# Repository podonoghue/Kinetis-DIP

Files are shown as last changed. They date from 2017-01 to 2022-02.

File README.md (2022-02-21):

# Kinetis-DIP
Kinetis MK22FN512VLH12 module in DIP format

The hardware design is an Altium designer project.  

Refer to the PDFs in the Project Outputs directory 

<a href="https://raw.githubusercontent.com/podonoghue/Kinetis-DIP/master/Hardware/Project%20Outputs%20for%20KinetisDIP/KinetisDIP.PDF">Main Board</img></a>

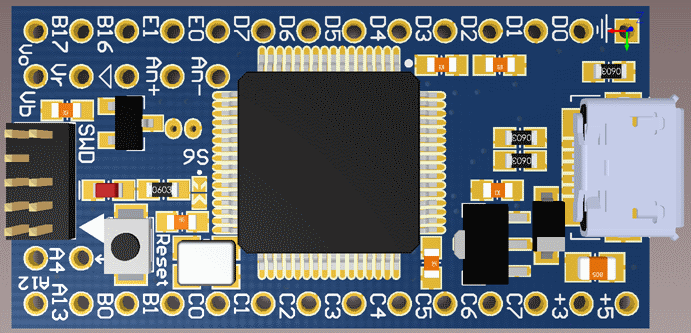
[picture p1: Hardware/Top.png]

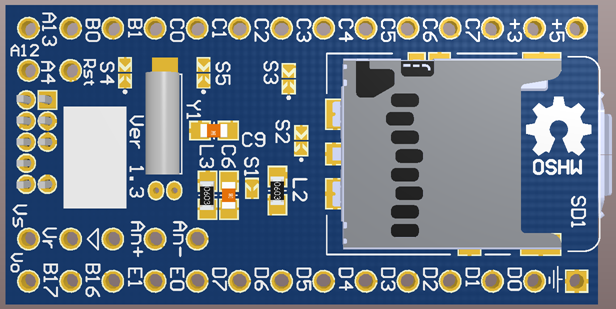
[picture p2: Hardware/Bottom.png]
An image Board Image - Bottom


====
PCBs may be ordered from OSH park

Main board

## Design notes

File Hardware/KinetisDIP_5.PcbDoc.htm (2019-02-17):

Reporting Options

# File in Previous Format

Date | : | 10/09/2017
Time | : | 6:38:27 PM
Filename | : | C:\Users\podonoghue\Documents\Development\PCB\Kinetis-DIP\Hardware\KinetisDIP_5.PcbDoc

Version | Warning
6.3 | CAUTION - Via connections to both hatched and solid signal layer polygons are now controlled by the polygon connect style rule. Re-pouring polygons may result in physical copper differences.
Summer 09 | CAUTION - File contains old violation objects. These violations are no longer supported & will not be loaded. Please run DRC after opening this file in order to refresh the violations.
Summer 09 | CAUTION - Existing testpoint rules and settings are used as fabrication testpoint information.
Altium Designer update 19 | CAUTION - Air Gap Width attribute was introduced to Polygon Connect Style Rule. Air Gap Width attribute now controls the distance between poured polygon and pads on the same net - this value was previosuly taken from clearance rule while ignoring net subscope leading to sometime unexpected results.
Release 13 | CAUTION - Silkscreen Over Component Pads Rules are converted to Silk To Solder Mask Clearance Rules. Suggest examining rule scopes for accuracy.
Release 14 | CAUTION - The Differential Pairs Routing rule added support for control of the width. Be aware that Width rules pertaining to differential pairs need to be manually moved to the Differential Pairs Routing rule.

This file was generated by an earlier version of the software

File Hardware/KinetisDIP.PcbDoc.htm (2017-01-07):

Reporting Options

# File in Previous Format

Date | : | 5/07/2016
Time | : | 8:55:03 AM
Filename | : | C:\Users\podonoghue\Documents\Development\USBDM\PCB\KinetisDIP\KinetisDIP.PcbDoc

Version | Warning
Summer 09 | CAUTION - File contains old violation objects. These violations are no longer supported & will not be loaded. Please run DRC after opening this file in order to refresh the violations.
Summer 09 | CAUTION - Existing testpoint rules and settings are used as fabrication testpoint information.
Release 12 | CAUTION - Air Gap Width previously controlled by Clearance rule is now controlled by Polygon Connect Style rule's newly introduced Air Gap Width (set to default value). Suggest reviewing each Polygon Connect Style rule's Air Gap Width attribute for correctness.
Release 13 | CAUTION - Silkscreen Over Component Pads Rules are converted to Silk To Solder Mask Clearance Rules. Suggest examining rule scopes for accuracy.

This file was generated by an earlier version of the software

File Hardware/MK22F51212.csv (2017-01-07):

Family | MK22F51212 | mk
Device | MK22FN512VDC12 | K22P121M120SF7RM | BGA_121
Device | MK22FN512VLL12 | K22P121M120SF7RM | LQFP_100
Device | MK22FN512VLH12 | K22P121M120SF7RM | LQFP_64
Device | MK22FN512VMP12 | K22P121M120SF7RM | BGA_64
Device | FRDM_K22F | K22P121M120SF8RM | FRDM_K22F
Device | MK22F_Module | K22P121M120SF8RM | MK22F_DIPModule
Key | Pin Name | pkg BGA_121 | pkg LQFP_100 | pkg LQFP_64 | pkg BGA_64 | Pkg FRDM_K22F | Pkg MK22F_DIPModule | Reset | Default | ALT0 | ALT1 | ALT2 | ALT3 | ALT4 | ALT5 | ALT6 | ALT7 | Seq | 121 BGA | 100 LQFP | 64 LQFP | 64 BGA
Pin | PTE0/CLKOUT32K | E4 | p1 | p1 | A1 | D14/J2_18/ConTx | p10_E0 | ADC1_SE4a |  | ADC1_SE4a | PTE0/CLKOUT32K | SPI1_PCS1 | UART1_TX |  |  | I2C1_SDA | RTC_CLKOUT | 1 | E4 | 1 | 1 | A1
Pin | PTE1/LLWU_P0 | E3 | p2 | p2 | B1 | D15/J2_19/ConRx | p11_E1 | ADC1_SE5a |  | ADC1_SE5a | PTE1/LLWU_P0 | SPI1_SOUT | UART1_RX |  |  | I2C1_SCL | SPI1_SIN | 2 | E3 | 2 | 2 | B1
Pin | PTE2/LLWU_P1 | E2 | p3 | * | * | * | * | ADC1_SE6a |  | ADC1_SE6a | PTE2/LLWU_P1 | SPI1_SCK | UART1_CTS_b |  |  |  |  | 3 | E2 | 3 | * | *
Pin | PTE3 | F4 | p4 | * | * | * | * | ADC1_SE7a |  | ADC1_SE7a | PTE3 | SPI1_SIN | UART1_RTS_b |  |  |  | SPI1_SOUT | 4 | F4 | 4 | * | *
Pin | PTE4/LLWU_P2 | H7 | p5 | * | * | * | * | DISABLED |  |  | PTE4/LLWU_P2 | SPI1_PCS0 | LPUART0_TX |  |  |  |  | 5 | H7 | 5 | * | *
Pin | PTE5 | G4 | p6 | * | * | * | * | DISABLED |  |  | PTE5 | SPI1_PCS2 | LPUART0_RX |  |  | FTM3_CH0 |  | 6 | G4 | 6 | * | *
Pin | PTE6 | F3 | p7 | * | * | * | * | DISABLED |  |  | PTE6 | SPI1_PCS3 | LPUART0_CTS_b | I2S0_MCLK |  | FTM3_CH1 | USB_SOF_OUT | 7 | F3 | 7 | * | *
Pin | VDD1 | E6 | p8 | p3 | C5 | VDD | Vdd | VDD1 |  |  |  |  |  |  |  |  |  | 8 | E6 | 8 | 3 | C5
Pin | VSS1 | G7 | p9 | p4 | C4 | VSS | Gnd | VSS1 |  |  |  |  |  |  |  |  |  | 9 | G7 | 9 | 4 | C4
Pin | VSS1a | L6 | * | * | * | * | * | VSS1a |  |  |  |  |  |  |  |  |  | 10 | L6 | * | * | *
Pin | USB0_DP | F1 | p10 | p5 | E1 | USB0_DP | USB0_DP | USB0_DP |  |  |  |  |  |  |  |  |  | 11 | F1 | 10 | 5 | E1
Pin | USB0_DM | F2 | p11 | p6 | D1 | USB0_DM | USB0_DM | USB0_DM |  |  |  |  |  |  |  |  |  | 12 | F2 | 11 | 6 | D1
Pin | VOUT33 | G1 | p12 | p7 | E2 | VOUT33 |  | VOUT33 |  |  |  |  |  |  |  |  |  | 13 | G1 | 12 | 7 | E2
Pin | VREGIN | G2 | p13 | p8 | D2 | VREGIN |  | VREGIN |  |  |  |  |  |  |  |  |  | 14 | G2 | 13 | 8 | D2
Pin | ADC0_DP1 | H1 | p14 | * | * | * | * | ADC0_DP1 |  |  |  |  |  |  |  |  |  | 15 | H1 | 14 | * | *
Pin | ADC0_DM1 | H2 | p15 | * | * | * | * | ADC0_DM1 |  |  |  |  |  |  |  |  |  | 16 | H2 | 15 | * | *
Pin | ADC1_DP1/ADC0_DP2 | J1 | p16 | * | * | * | * | ADC1_DP1/ADC0_DP2 |  |  |  |  |  |  |  |  |  | 17 | J1 | 16 | * | *
Pin | ADC1_DM1/ADC0_DM2 | J2 | p17 | * | * | * | * | ADC1_DM1/ADC0_DM2 |  |  |  |  |  |  |  |  |  | 18 | J2 | 17 | * | *
Pin | ADC0_DP0/ADC1_DP3 | K1 | p18 | p9 | G1 | A6/J24_1 | p11b_An_plus | ADC0_DP0/ADC1_DP3/ADC0_SE0 |  |  |  |  |  |  |  |  |  | 19 | K1 | 18 | 9 | G1
Pin | ADC0_DM0/ADC1_DM3 | K2 | p19 | p10 | F1 | A7/J24_3 | p10b_An_minus | ADC0_DM0/ADC1_DM3/ADC0_SE19 |  |  |  |  |  |  |  |  |  | 20 | K2 | 19 | 10 | F1
Pin | ADC1_DP0/ADC0_DP3 | L1 | p20 | p11 | G2 | A8/J24_5 |  | ADC1_DP0/ADC0_DP3/ADC1_SE0/ADC0_SE3 |  |  |  |  |  |  |  |  |  | 21 | L1 | 20 | 11 | G2
Pin | ADC1_DM0/ADC0_DM3 | L2 | p21 | p12 | F2 | A9/J24_7 |  | ADC1_DM0/ADC0_DM3/ADC1_SE19 |  |  |  |  |  |  |  |  |  | 22 | L2 | 21 | 12 | F2
Pin | VDDA | F5 | p22 | p13 | F4 | VDDA | Vdd | VDDA |  |  |  |  |  |  |  |  |  | 23 | F5 | 22 | 13 | F4
Pin | VREFH | G5 | p23 | p14 | G4 | VREFH | p13b_Vr | VREFH |  |  |  |  |  |  |  |  |  | 24 | G5 | 23 | 14 | G4
Pin | VREFL | G6 | p24 | p15 | G3 | VREFL | p12b_Agnd | VREFL |  |  |  |  |  |  |  |  |  | 25 | G6 | 24 | 15 | G3
Pin | VSSA | F6 | p25 | p16 | F3 | VSSA | p12b_Agnd | VSSA |  |  |  |  |  |  |  |  |  | 26 | F6 | 25 | 16 | F3
Pin | ADC1_SE16/ADC0_SE22 | J3 | * | * | * | * | * | ADC1_SE16/ADC0_SE22 |  |  |  |  |  |  |  |  |  | 27 | J3 | * | * | *
Pin | ADC0_SE16/CMP1_IN2/ADC0_SE21 | H3 | * | * | * | * | * | ADC0_SE16/CMP1_IN2/ADC0_SE21 |  |  |  |  |  |  |  |  |  | 28 | H3 | * | * | *
Pin | VREF_OUT/CMP1_IN5/CMP0_IN5/ADC1_SE18 | L3 | p26 | p17 | H1 | D24 |  | VREF_OUT/CMP1_IN5/CMP0_IN5/ADC1_SE18 |  |  |  |  |  |  |  |  |  | 29 | L3 | 26 | 17 | H1
Pin | DAC0_OUT/CMP1_IN3/ADC0_SE23 | K5 | p27 | p18 | H2 | A11/J24_11 | p14_Vo | DAC0_OUT/CMP1_IN3/ADC0_SE23 |  |  |  |  |  |  |  |  |  | 30 | K5 | 27 | 18 | H2
Pin | DAC1_OUT/CMP0_IN4/ADC1_SE23 | K4 | * | * | * | * | * | DAC1_OUT/CMP0_IN4/ADC1_SE23 |  |  |  |  |  |  |  |  |  | 31 | K4 | * | * | *
Pin | RTC_WAKEUP_b | L7 | * | * | * | * | * | RTC_WAKEUP_b |  |  |  |  |  |  |  |  |  | 32 | L7 | * | * | *
Pin | XTAL32 | L4 | p28 | p19 | H3 | XTAL32 | xtal_32kHz | XTAL32 |  |  |  |  |  |  |  |  |  | 33 | L4 | 28 | 19 | H3
Pin | EXTAL32 | L5 | p29 | p20 | H4 | EXTAL32 | extal_32kHz | EXTAL32 |  |  |  |  |  |  |  |  |  | 34 | L5 | 29 | 20 | H4
Pin | VBAT | K6 | p30 | p21 | H5 | VBAT | p14b_Vs | VBAT |  |  |  |  |  |  |  |  |  | 35 | K6 | 30 | 21 | H5
Pin | PTE24 | H5 | p31 | * | * | * | * | ADC0_SE17 |  | ADC0_SE17 | PTE24 |  |  |  | I2C0_SCL | EWM_OUT_b |  | 36 | H5 | 31 | * | *
Pin | PTE25 | J5 | p32 | * | * | * | * | ADC0_SE18 |  | ADC0_SE18 | PTE25 |  |  |  | I2C0_SDA | EWM_IN |  | 37 | J5 | 32 | * | *
Pin | PTE26/CLKOUT32K | H6 | p33 | * | * | * | * | DISABLED |  |  | PTE26/CLKOUT32K |  |  |  |  | RTC_CLKOUT | USB_CLKIN | 38 | H6 | 33 | * | *
Pin | PTA0 | J6 | p34 | p22 | D3 | SWD_CLK | SWD_CLK | JTAG_TCLK/SWD_CLK |  |  | PTA0 | UART0_CTS_b | FTM0_CH5 |  |  |  | JTAG_TCLK/SWD_CLK | 39 | J6 | 34 | 22 | D3
Pin | PTA1 | H8 | p35 | p23 | D4 | D9/J2_4/LED_RED | SWD_RX | JTAG_TDI |  |  | PTA1 | UART0_RX | FTM0_CH6 |  |  |  | JTAG_TDI | 40 | H8 | 35 | 23 | D4
Pin | PTA2 | J7 | p36 | p24 | E5 | D3/J1_8/LED_GREEN | SWD_TX | JTAG_TDO/TRACE_SWO |  |  | PTA2 | UART0_TX | FTM0_CH7 |  |  |  | JTAG_TDO/TRACE_SWO | 41 | J7 | 36 | 24 | E5
Pin | PTA3 | H9 | p37 | p25 | D5 | SWD_DIO | SWD_DIO | JTAG_TMS/SWD_DIO |  |  | PTA3 | UART0_RTS_b | FTM0_CH0 |  |  |  | JTAG_TMS/SWD_DIO | 42 | H9 | 37 | 25 | D5
Pin | PTA4/LLWU_P3 | J8 | p38 | p26 | G5 | D4/J1_10 | p15b_A4 | NMI_b |  |  | PTA4/LLWU_P3 |  | FTM0_CH1 |  |  |  | NMI_b | 43 | J8 | 38 | 26 | G5
Pin | PTA5 | K7 | p39 | p27 | F5 | D16/J1_1 |  | JTAG_TRST_b |  |  | PTA5 | USB_CLKIN | FTM0_CH2 |  |  | I2S0_TX_BCLK | JTAG_TRST_b | 44 | K7 | 39 | 27 | F5
Pin | VDD2 | E5 | p40 | * | * | * | * | VDD2 |  |  |  |  |  |  |  |  |  | 45 | E5 | 40 | * | *
Pin | VSS2 | G3 | p41 | * | * | * | * | VSS2 |  |  |  |  |  |  |  |  |  | 46 | G3 | 41 | * | *
Pin | PTA10 | J9 | * | * | * | * | * | DISABLED |  |  | PTA10 |  | FTM2_CH0 |  |  | FTM2_QD_PHA |  | 47 | J9 | * | * | *
Pin | PTA11 | J4 | * | * | * | * | * | DISABLED |  |  | PTA11 |  | FTM2_CH1 |  |  | FTM2_QD_PHB |  | 48 | J4 | * | * | *
Pin | PTA12 | K8 | p42 | p28 | H6 | D18/J1_5 | p16_A12 | DISABLED |  |  | PTA12 |  | FTM1_CH0 |  |  | I2S0_TXD0 | FTM1_QD_PHA | 49 | K8 | 42 | 28 | H6
Pin | PTA13/LLWU_P4 | L8 | p43 | p29 | G6 | D17/J1_3 | p15_A13 | DISABLED |  |  | PTA13/LLWU_P4 |  | FTM1_CH1 |  |  | I2S0_TX_FS | FTM1_QD_PHB | 50 | L8 | 43 | 29 | G6
Pin | PTA14 | K9 | p44 | * | * | * | * | DISABLED |  |  | PTA14 | SPI0_PCS0 | UART0_TX |  |  | I2S0_RX_BCLK |  | 51 | K9 | 44 | * | *
Pin | PTA15 | L9 | p45 | * | * | * | * | DISABLED |  |  | PTA15 | SPI0_SCK | UART0_RX |  |  | I2S0_RXD0 |  | 52 | L9 | 45 | * | *
Pin | PTA16 | J10 | p46 | * | * | * | * | DISABLED |  |  | PTA16 | SPI0_SOUT | UART0_CTS_b |  |  | I2S0_RX_FS |  | 53 | J10 | 46 | * | *
Pin | PTA17 | H10 | p47 | * | * | * | * | ADC1_SE17 |  | ADC1_SE17 | PTA17 | SPI0_SIN | UART0_RTS_b |  |  | I2S0_MCLK |  | 54 | H10 | 47 | * | *
Pin | VDD3 | L10 | p48 | p30 | G7 | VDD | Vdd | VDD3 |  |  |  |  |  |  |  |  |  | 55 | L10 | 48 | 30 | G7
Pin | VSS3 | K10 | p49 | p31 | H7 | VSS | Gnd | VSS3 |  |  |  |  |  |  |  |  |  | 56 | K10 | 49 | 31 | H7
Pin | PTA18 | L11 | p50 | p32 | H8 | EXTAL0 | extal_24MHz | EXTAL0 |  | EXTAL0 | PTA18 |  | FTM0_FLT2 | FTM_CLKIN0 |  |  |  | 57 | L11 | 50 | 32 | H8
Pin | PTA19 | K11 | p51 | p33 | G8 | XTAL0 | xtal_24MHz | XTAL0 |  | XTAL0 | PTA19 |  | FTM1_FLT0 | FTM_CLKIN1 |  | LPTMR0_ALT1 |  | 58 | K11 | 51 | 33 | G8
Pin | RESET_b | J11 | p52 | p34 | F8 | RESET_b | p16b_Rst | RESET_b |  |  |  |  |  |  |  |  |  | 59 | J11 | 52 | 34 | F8
Pin | PTA29 | H11 | * | * | * | * | * | DISABLED |  |  | PTA29 |  |  |  |  | FB_A24 |  | 60 | H11 | * | * | *
Pin | PTB0/LLWU_P5 | G11 | p53 | p35 | F7 | A0/J24_2 | p17_B0 | ADC0_SE8/ADC1_SE8 |  | ADC0_SE8/ADC1_SE8 | PTB0/LLWU_P5 | I2C0_SCL | FTM1_CH0 |  |  | FTM1_QD_PHA |  | 61 | G11 | 53 | 35 | F7
Pin | PTB1 | G10 | p54 | p36 | F6 | A1/J24_4 | p18_B1 | ADC0_SE9/ADC1_SE9 |  | ADC0_SE9/ADC1_SE9 | PTB1 | I2C0_SDA | FTM1_CH1 |  |  | FTM1_QD_PHB |  | 62 | G10 | 54 | 36 | F6
Pin | PTB2 | G9 | p55 | p37 | E7 | A5/J24_12/ONBOARD_SCL | p17_B0_alt | ADC0_SE12 |  | ADC0_SE12 | PTB2 | I2C0_SCL | UART0_RTS_b |  |  | FTM0_FLT3 |  | 63 | G9 | 55 | 37 | E7
Pin | PTB3 | G8 | p56 | p38 | E8 | A4/J24_10/ONBOARD_SDA | p18_B1_alt | ADC0_SE13 |  | ADC0_SE13 | PTB3 | I2C0_SDA | UART0_CTS_b |  |  | FTM0_FLT0 |  | 64 | G8 | 56 | 38 | E8
Pin | PTB6 | F11 | * | * | * | * | * | ADC1_SE12 |  | ADC1_SE12 | PTB6 |  |  |  | FB_AD23 |  |  | 65 | F11 | * | * | *
Pin | PTB7 | E11 | * | * | * | * | * | ADC1_SE13 |  | ADC1_SE13 | PTB7 |  |  |  | FB_AD22 |  |  | 66 | E11 | * | * | *
Pin | PTB8 | D11 | * | * | * | * | * | DISABLED |  |  | PTB8 |  | LPUART0_RTS_b |  | FB_AD21 |  |  | 67 | D11 | * | * | *
Pin | PTB9 | E10 | p57 | * | * | * | * | DISABLED |  |  | PTB9 | SPI1_PCS1 | LPUART0_CTS_b |  | FB_AD20 |  |  | 68 | E10 | 57 | * | *
Pin | PTB10 | D10 | p58 | * | * | * | * | ADC1_SE14 |  | ADC1_SE14 | PTB10 | SPI1_PCS0 | LPUART0_RX |  | FB_AD19 | FTM0_FLT1 |  | 69 | D10 | 58 | * | *
Pin | PTB11 | C10 | p59 | * | * | * | * | ADC1_SE15 |  | ADC1_SE15 | PTB11 | SPI1_SCK | LPUART0_TX |  | FB_AD18 | FTM0_FLT2 |  | 70 | C10 | 59 | * | *
Pin | VSS4 | * | p60 | * | * | * | * | VSS4 |  |  |  |  |  |  |  |  |  | 71 | * | 60 | * | *
Pin | VDD4 | * | p61 | * | * | * | * | VDD4 |  |  |  |  |  |  |  |  |  | 72 | * | 61 | * | *
Pin | PTB16 | B10 | p62 | p39 | E6 | D2/J1_6/SD_DETECT | p12_B16 | DISABLED |  |  | PTB16 | SPI1_SOUT | UART0_RX | FTM_CLKIN0 | FB_AD17 | EWM_IN |  | 73 | B10 | 62 | 39 | E6
Pin | PTB17 | E9 | p63 | p40 | D7 | SW3 | p13_B17 | DISABLED |  |  | PTB17 | SPI1_SIN | UART0_TX | FTM_CLKIN1 | FB_AD16 | EWM_OUT_b |  | 74 | E9 | 63 | 40 | D7
Pin | PTB18 | D9 | p64 | p41 | D6 | D5/J1_12 | p12_B16_alt | DISABLED |  |  | PTB18 |  | FTM2_CH0 | I2S0_TX_BCLK | FB_AD15 | FTM2_QD_PHA |  | 75 | D9 | 64 | 41 | D6
Pin | PTB19 | C9 | p65 | p42 | C7 | D8/J2_2 | p13_B17_alt | DISABLED |  |  | PTB19 |  | FTM2_CH1 | I2S0_TX_FS | FB_OE_b | FTM2_QD_PHB |  | 76 | C9 | 65 | 42 | C7
Pin | PTB20 | F10 | p66 | * | * | * | * | DISABLED |  |  | PTB20 |  |  |  | FB_AD31 | CMP0_OUT |  | 77 | F10 | 66 | * | *
Pin | PTB21 | F9 | p67 | * | * | * | * | DISABLED |  |  | PTB21 |  |  |  | FB_AD30 | CMP1_OUT |  | 78 | F9 | 67 | * | *
Pin | PTB22 | F8 | p68 | * | * | * | * | DISABLED |  |  | PTB22 |  |  |  | FB_AD29 |  |  | 79 | F8 | 68 | * | *
Pin | PTB23 | E8 | p69 | * | * | * | * | DISABLED |  |  | PTB23 |  | SPI0_PCS5 |  | FB_AD28 |  |  | 80 | E8 | 69 | * | *
Pin | PTC0 | B9 | p70 | p43 | D8 | USB_FLAG | p19_C0 | ADC0_SE14 |  | ADC0_SE14 | PTC0 | SPI0_PCS4 | PDB0_EXTRG | USB_SOF_OUT | FB_AD14 |  |  | 81 | B9 | 70 | 43 | D8
Pin | PTC1/LLWU_P6 | D8 | p71 | p44 | C6 | A2/J24_6/SW2 | p20_C1 | ADC0_SE15 |  | ADC0_SE15 | PTC1/LLWU_P6 | SPI0_PCS3 | UART1_RTS_b | FTM0_CH0 | FB_AD13 | I2S0_TXD0 | LPUART0_RTS_b | 82 | D8 | 71 | 44 | C6
Pin | PTC2 | C8 | p72 | p45 | B7 | A3/J24_8 | p21_C2 | ADC0_SE4b/CMP1_IN0 |  | ADC0_SE4b/CMP1_IN0 | PTC2 | SPI0_PCS2 | UART1_CTS_b | FTM0_CH1 | FB_AD12 | I2S0_TX_FS | LPUART0_CTS_b | 83 | C8 | 72 | 45 | B7
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

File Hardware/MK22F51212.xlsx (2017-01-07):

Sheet: MK22F51212
Pin Name | Pkg MK22F_DIPModule | MUX(7) | MUX(6) | MUX(4) | MUX(3) | MUX(2) | MUX(1) | MUX(0) | ALT5 | MUX(0) | MUX(1) | MUX(2) | MUX(3) | MUX(4) | MUX(6) | MUX(7)
PTD0/LLWU_P12 | p2_D0 |  | LPUART0_RTS | FTM3_CH0 | UART2_RTS | SPI0_PCS0 | PTD0 LLWU_P12 |  | FB_ALE/FB_CS1/FB_TS
PTD1 | p3_D1 |  | LPUART0_CTS | FTM3_CH1 | UART2_CTS | SPI0_SCK | PTD1 | ADC0_SE5b | FB_CS0 | CMP0_IN1 | PTC7 | SPI0_SIN | USB_SOF_OUT | I2S0_RX_FS
PTD2/LLWU_P13 | p4_D2 | I2C0_SCL | LPUART0_RX | FTM3_CH2 | UART2_RX | SPI0_SOUT | PTD2 LLWU_P13 |  | FB_AD4 | CMP0_IN0 | PTC6 LLWU_P10 | SPI0_SOUT | PDB0_EXTRG | I2S0_RXCLK | I2S0_MCLK
PTD3 | p5_D3 | I2C0_SDA | LPUART0_TX | FTM3_CH3 | UART2_TX | SPI0_SIN | PTD3 |  | FB_AD3 |  | PTC5 LLWU_P9 | SPI0_SCK | LPTMR0_ALT2 | I2S0_RXD0 | CMP0_OUT | FTM0_CH2
PTD4/LLWU_P14 | p6_D4 | SPI1_PCS0 | EWM_IN | FTM0_CH4 | UART0_RTS | SPI0_PCS1 | PTD4 LLWU_P14 |  | FB_AD2 |  | PTC4 LLWU_P8 | SPI0_PCS0 | UART1_TX | FTM0_CH3 | CMP1_OUT | LPUART0_TX
PTD5 | p7_D5 | SPI1_SCK | EWM_OUT | FTM0_CH5 | UART0_CTS | SPI0_PCS2 | PTD5 | ADC0_SE6b | FB_AD1 | CMP1_IN1 | PTC3 LLWU_P7 | SPI0_PCS1 | UART1_RX | FTM0_CH2 | I2S0_TXCLK | LPUART0_RX
PTD6/LLWU_P15 | p8_D6 | SPI1_SOUT | FTM0_FLT0 | FTM0_CH6 | UART0_RX | SPI0_PCS3 | PTD6 LLWU_P15 | ADC0_SE7b | FB_AD0 | ADC0_SE4b CMP1_IN0 | PTC2 | SPI0_PCS2 | UART1_CTS | FTM0_CH1 | I2S0_TX_FS | LPUART0_CTS
PTD7 | p9_D7 | SPI1_SIN | FTM0_FLT1 | FTM0_CH7 | UART0_TX |  | PTD7 |  |  | ADC0_SE15 | PTC1 LLWU_P6 | SPI0_PCS3 | UART1_RTS | FTM0_CH0 | I2S0_TXD0 | LPUART0_RTS
PTE0/CLKOUT32K | p10_E0 | RTC_CLKOUT | I2C1_SDA |  | UART1_TX | SPI1_PCS1 | PTE0 CLKOUT32K | ADC1_SE4a |  | ADC0_SE14 | PTC0 | SPI0_PCS4 | PDB0_EXTRG | USB_SOF_OUT
PTE1/LLWU_P0 | p11_E1 | SPI1_SIN | I2C1_SCL |  | UART1_RX | SPI1_SOUT | PTE1 LLWU_P0 | ADC1_SE5a |  | ADCx_SE9 | PTB1 | I2C0_SDA | FTM1_CH1 |  | FTM1_QD_PHB
PTB16 | p12_B16 |  | EWM_IN | FTM_CLKIN0 | UART0_RX | SPI1_SOUT | PTB16 |  | FB_AD17 | ADCx_SE8 | PTB0 LLWU_P5 | I2C0_SCL | FTM1_CH0 |  | FTM1_QD_PHA
PTB17 | p13_B17 |  | EWM_OUT | FTM_CLKIN1 | UART0_TX | SPI1_SIN | PTB17 |  | FB_AD16 |  | PTA12 |  | FTM1_CH0 |  | I2S0_TXD0 | FTM1_QD_PHA
DAC0_OUT/CMP1_IN3/ADC0_SE23 | p14_Vo |  |  |  |  | DAC0_OUT/CMP1_IN3/ADC0_SE23 |  |  |  |  | PTA13 LLWU_P4 |  | FTM1_CH1 |  | I2S0_TX_FS | FTM1_QD_PHB
PTC7 | p26_C7 | CMP0_IN1 | PTC7 | SPI0_SIN | USB_SOF_OUT | I2S0_RX_FS |  |  | FB_AD8
PTC6/LLWU_P10 | p25_C6 | CMP0_IN0 | PTC6/LLWU_P10 | SPI0_SOUT | PDB0_EXTRG | I2S0_RXCLK | I2S0_MCLK |  | FB_AD9
PTC5/LLWU_P9 | p24_C5 |  | PTC5/LLWU_P9 | SPI0_SCK | LPTMR0_ALT2 | I2S0_RXD0 | CMP0_OUT | FTM0_CH2 | FB_AD10
PTC4/LLWU_P8 | p23_C4 |  | PTC4/LLWU_P8 | SPI0_PCS0 | UART1_TX | FTM0_CH3 | CMP1_OUT | LPUART0_TX | FB_AD11
PTC3/LLWU_P7 | p22_C3 | CMP1_IN1 | PTC3/LLWU_P7 | SPI0_PCS1 | UART1_RX | FTM0_CH2 | I2S0_TXCLK | LPUART0_RX | CLKOUT
PTC2 | p21_C2 | ADC0_SE4b/ CMP1_IN0 | PTC2 | SPI0_PCS2 | UART1_CTS | FTM0_CH1 | I2S0_TX_FS | LPUART0_CTS | FB_AD12
PTC1/LLWU_P6 | p20_C1 | ADC0_SE15 | PTC1/LLWU_P6 | SPI0_PCS3 | UART1_RTS | FTM0_CH0 | I2S0_TXD0 | LPUART0_RTS | FB_AD13
PTC0 | p19_C0 | ADC0_SE14 | PTC0 | SPI0_PCS4 | PDB0_EXTRG | USB_SOF_OUT |  |  | FB_AD14
PTB1 | p181 | ADCx_SE9 | PTB1 | I2C0_SDA | FTM1_CH1 |  | FTM1_QD_PHB
PTB0/LLWU_P5 | p170 | ADCx_SE8 | PTB0/LLWU_P5 | I2C0_SCL | FTM1_CH0 |  | FTM1_QD_PHA
PTA12 | p16_A12 |  | PTA12 |  | FTM1_CH0 |  | I2S0_TXD0 | FTM1_QD_PHA
PTA13/LLWU_P4 | p15_A13 |  | PTA13/LLWU_P4 |  | FTM1_CH1 |  | I2S0_TX_FS | FTM1_QD_PHB
PTB3 | p181_alt | ADC0_SE13 | PTB3 | I2C0_SDA | UART0_CTS |  | FTM0_FLT0
PTB19 | p1317_alt |  | PTB19 |  | FTM2_CH1 | I2S0_TX_FS | FTM2_QD_PHB |  | FB_OE
PTB18 | p1216_alt |  | PTB18 |  | FTM2_CH0 | I2S0_TXCLK | FTM2_QD_PHA |  | FB_AD15
PTB2 | p170_alt | ADC0_SE12 | PTB2 | I2C0_SCL | UART0_RTS |  | FTM0_FLT3
RESET | p16b_Rst
ADC0_DM0/ADC1_DM3 | p10b_An_minus
ADC0_DP0/ADC1_DP3 | p11b_An_plus
VREFH | p13b_Vr
VBAT | p14b_Vb
PTA4/LLWU_P3 | p15b_A4 |  | PTA4/LLWU_P3 |  | FTM0_CH1 |  |  | NMI
PTA5 | LED |  | PTA5 | USB_CLKIN | FTM0_CH2 |  | I2S0_TXCLK | JTAG_TRST
PTC8 | SD_SW | ADC1_SE4b/ CMP0_IN2 | PTC8 |  | FTM3_CH4 | I2S0_MCLK |  |  | FB_AD7
PTC9 |  | ADC1_SE5b/ CMP0_IN3 | PTC9 |  | FTM3_CH5 | I2S0_RXCLK | FTM2_FLT0 |  | FB_AD6
PTC10 |  | ADC1_SE6b | PTC10 | I2C1_SCL | FTM3_CH6 | I2S0_RX_FS |  |  | FB_AD5
PTA19 | xtal_24MHz | XTAL0 | PTA19 |  | FTM1_FLT0 | FTM_CLKIN1 | LPTMR0_ALT1
XTAL32 | xtal_32kHz
PTA18 | extal_24MHz | EXTAL0 | PTA18 |  | FTM0_FLT2 | FTM_CLKIN0
EXTAL32 | extal_32kHz

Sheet: Sheet1
MUX(7) | MUX(6) | MUX(4) | MUX(3) | MUX(2) | MUX(1) | MUX(0) | ALT5 | MUX(0) | MUX(1) | MUX(2) | MUX(3) | MUX(4) | MUX(6) | MUX(7)
 |  |  |  |  |  | Gnd |  | Vusb, 5V IN
 | LPUART0_RTS | FTM3_CH0 | UART2_RTS | SPI0_PCS0 | PTD0 LLWU_P12 |  | FB_ALE/FB_CS1/FB_TS | Vdd = 3.3V
 | LPUART0_CTS | FTM3_CH1 | UART2_CTS | SPI0_SCK | PTD1 | ADC0_SE5b | FB_CS0 | CMP0_IN1 | PTC7 | SPI0_SIN | USB_SOF_OUT | I2S0_RX_FS
I2C0_SCL | LPUART0_RX | FTM3_CH2 | UART2_RX | SPI0_SOUT | PTD2 LLWU_P13 |  | FB_AD4 | CMP0_IN0 | PTC6 LLWU_P10 | SPI0_SOUT | PDB0_EXTRG | I2S0_RXCLK | I2S0_MCLK
I2C0_SDA | LPUART0_TX | FTM3_CH3 | UART2_TX | SPI0_SIN | PTD3 |  | FB_AD3 |  | PTC5 LLWU_P9 | SPI0_SCK | LPTMR0_ALT2 | I2S0_RXD0 | CMP0_OUT | FTM0_CH2
SPI1_PCS0 | EWM_IN | FTM0_CH4 | UART0_RTS | SPI0_PCS1 | PTD4 LLWU_P14 |  | FB_AD2 |  | PTC4 LLWU_P8 | SPI0_PCS0 | UART1_TX | FTM0_CH3 | CMP1_OUT | LPUART0_TX
SPI1_SCK | EWM_OUT | FTM0_CH5 | UART0_CTS | SPI0_PCS2 | PTD5 | ADC0_SE6b | FB_AD1 | CMP1_IN1 | PTC3 LLWU_P7 | SPI0_PCS1 | UART1_RX | FTM0_CH2 | I2S0_TXCLK | LPUART0_RX
SPI1_SOUT | FTM0_FLT0 | FTM0_CH6 | UART0_RX | SPI0_PCS3 | PTD6 LLWU_P15 | ADC0_SE7b | FB_AD0 | ADC0_SE4b CMP1_IN0 | PTC2 | SPI0_PCS2 | UART1_CTS | FTM0_CH1 | I2S0_TX_FS | LPUART0_CTS
SPI1_SIN | FTM0_FLT1 | FTM0_CH7 | UART0_TX |  | PTD7 |  |  | ADC0_SE15 | PTC1 LLWU_P6 | SPI0_PCS3 | UART1_RTS | FTM0_CH0 | I2S0_TXD0 | LPUART0_RTS
RTC_CLKOUT | I2C1_SDA |  | UART1_TX | SPI1_PCS1 | PTE0 CLKOUT32K | ADC1_SE4a |  | ADC0_SE14 | PTC0 | SPI0_PCS4 | PDB0_EXTRG | USB_SOF_OUT
SPI1_SIN | I2C1_SCL |  | UART1_RX | SPI1_SOUT | PTE1 LLWU_P0 | ADC1_SE5a |  | ADCx_SE9 | PTB1 | I2C0_SDA | FTM1_CH1 |  | FTM1_QD_PHB
 | EWM_IN | FTM_CLKIN0 | UART0_RX | SPI1_SOUT | PTB16 |  | FB_AD17 | ADCx_SE8 | PTB0 LLWU_P5 | I2C0_SCL | FTM1_CH0 |  | FTM1_QD_PHA
 | EWM_OUT | FTM_CLKIN1 | UART0_TX | SPI1_SIN | PTB17 |  | FB_AD16 |  | PTA12 |  | FTM1_CH0 |  | I2S0_TXD0 | FTM1_QD_PHA
 |  |  | DAC0_OUT/CMP1_IN3/ADC0_SE23 |  |  |  |  |  | PTA13 LLWU_P4 |  | FTM1_CH1 |  | I2S0_TX_FS | FTM1_QD_PHB

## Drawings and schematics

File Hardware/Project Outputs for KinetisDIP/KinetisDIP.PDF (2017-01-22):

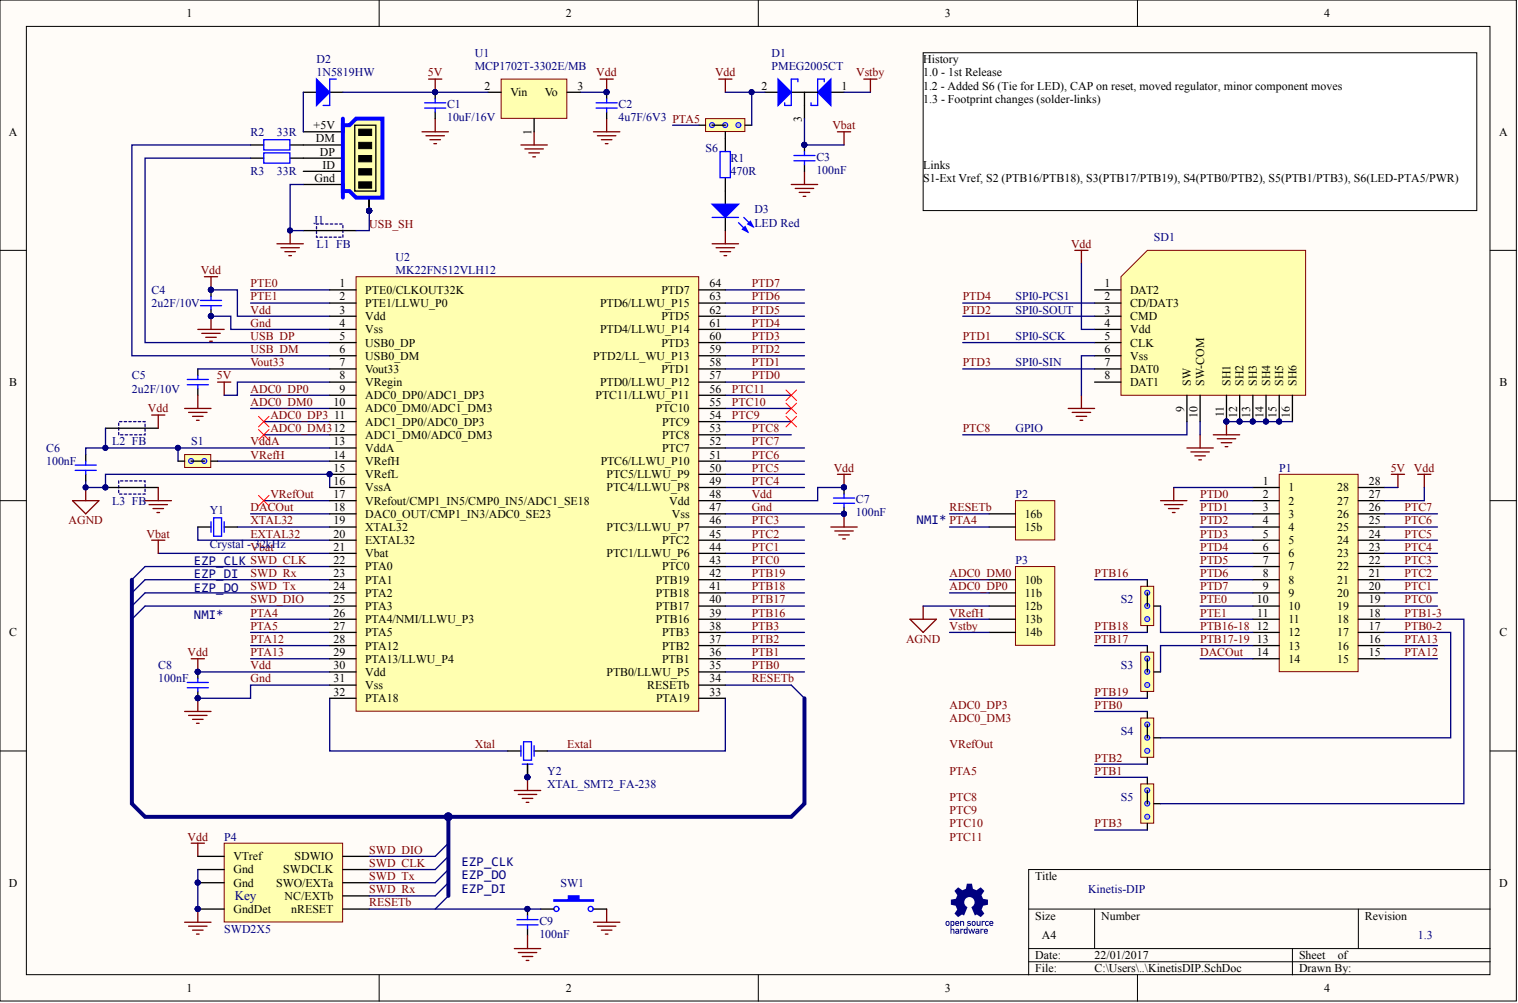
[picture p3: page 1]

History
1.0 - 1st Release
1.2 - Added S6 (Tie for LED), CAP on reset, moved regulator, minor component moves
1.3 - Footprint changes (solder-links)

Links
S1-Ext Vref, S2 (PTB16/PTB18), S3(PTB17/PTB19), S4(PTB0/PTB2), S5(PTB1/PTB3), S6(LED-PTA5/PWR)

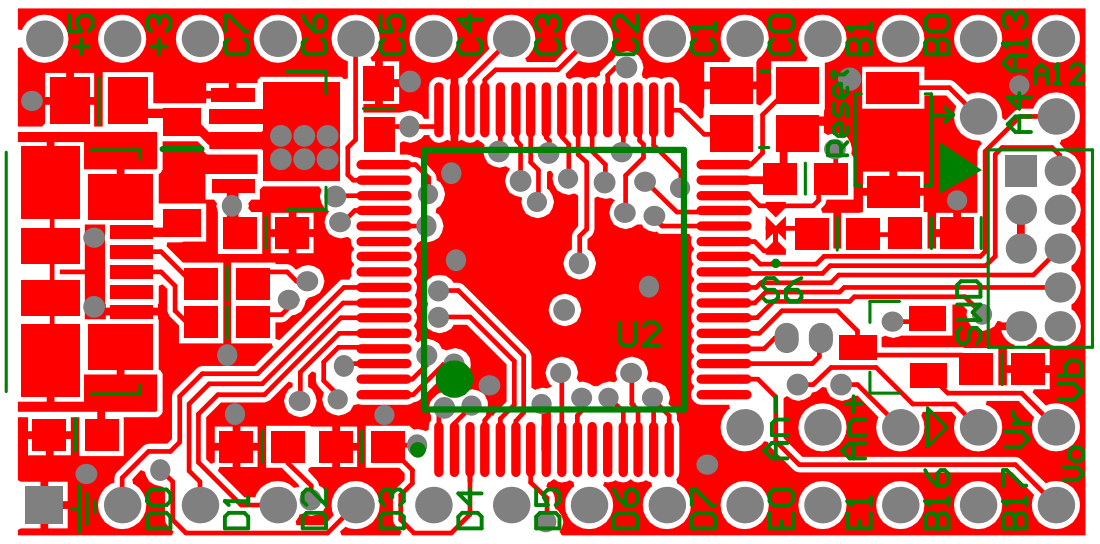
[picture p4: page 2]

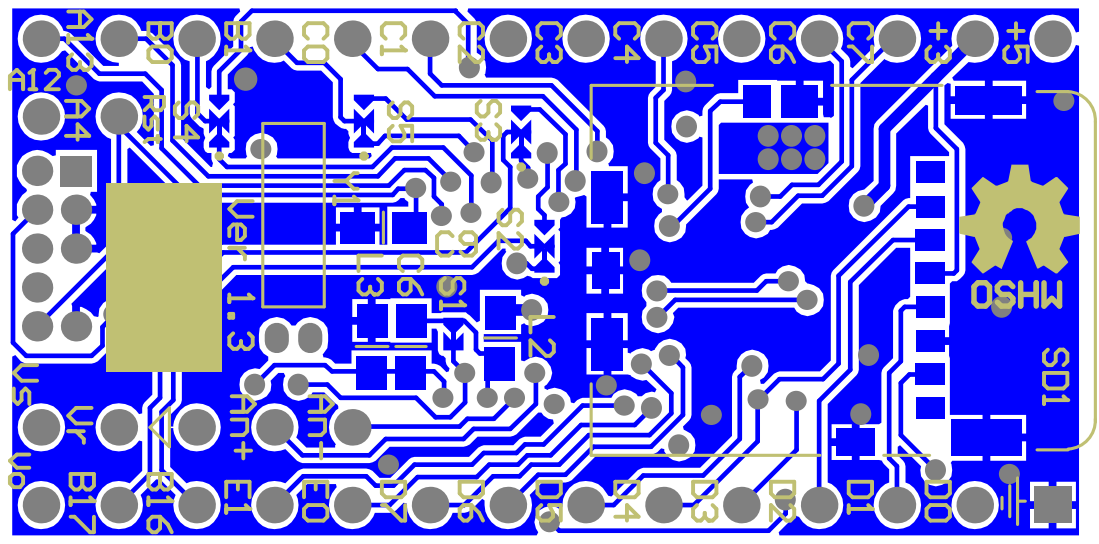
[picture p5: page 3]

Bill of Materials | Kinetis-DIP
Source Data From: | KinetisDIP.PrjPCB
Project: | KinetisDIP.PrjPCB
Variant: | None
Creation Date: | 22/01/2017 | 1:08:23 PM
Print Date: | 22-Jan-17 | 1:08:30 PM
Footprint | Comment | Farnell PN | Digikey | Designator | Description | Quantity
CCNP2012-0805 | 10uF/16V | 2346934 | | C1 | Capacitor SMT 0805 | 1
CCNP1608-0603 | 4u7F/6V3 | 1907504 | | C2 | Capacitor SMT 0603 | 1
CCNP1608-0603 | 100nF | | | C3, C6, C7, C8, C9 | Capacitor SMT 0603 | 5
CCNP1608-0603 | 2u2F/10V | 2496850 | | C4, C5 | Capacitor | 2
SOT23 | PMEG2005CT | 2459194 | | D1 | Dual Schottky Diode (SMT) | 1
SOD-123 | 1N5819HW | 2306459 | | D2 | SCHOTTKY, 1A, 40V, SOD-123 | 1
LED1608-0603-RED | LED Red | 5790852 | | D3 | LED 0603 Red | 1
MOLEX - 47346-0001 | USB_MICRO_B_CONNECTOR | 1568026 | | J1 | USB Micro-B Connector | 1
CR1608-0603 | FB | 1515717 | | L1, L2, L3 | Ferrite Bead (0603) | 3
SWD-2x5 | SWD2X5 | | | P4 | SWD Connector 2x5-Pin | 1
CR1608-0603 | 470R | 1632490 | | R1 | Resistor SMT | 1
CR1608-0603 | 33R | | | R2, R3 | Resistor | 2
SDCARD_MICRO - MOLEX 504077-1891 | SD_Socket2 | 2214964 | | SD1 | MOLEX 5040771891 CONNECTOR, MICRO SD, 1.1MM, 8 POSITION | 1
SW_SMT_PB2-B3U | SW-PB-SMT-B3U | 2500851 | | SW1 | Switch OMRON B3U series | 1
SOT-89 | MCP1702T-3302E/MB | 1605558 | | U1 | 3V3 LDO regulator | 1
TSQFP50P1200X1200-64N | MK22FN512VLH12 | 2434224 | | U2 | Arm Cortex M4F | 1
crystal_can | Crystal - 32kHz | 1457084 | | Y1 | CITIZEN CFS2016 | 1
Crystal_SMT - EPSON-FA-238 | XTAL_SMT2_FA-238 | 1712815 | | Y2 | Crystal (EPSON Q22FA23800065 FA-238 24 MHZ 12.0PF) | 1
| | | | | | 26
Approved | | Notes

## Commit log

2017-01-07 V1.2 Initial commit
    [KinetisDIP.GBL, KinetisDIP.GBO, KinetisDIP.GBP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]
2017-01-21 V1.3 Minor changes
    [KinetisDIP.GBL, KinetisDIP.GBO, KinetisDIP.GBP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]
2017-01-22 V1.3 Cosmetic changes
    [KinetisDIP.PcbDoc]
